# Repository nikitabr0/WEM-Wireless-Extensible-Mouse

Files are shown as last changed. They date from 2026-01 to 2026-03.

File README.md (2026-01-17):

# WEM-Wireless-Extensible-Mouse
A computer mouse, that can be connected via USB-C, Bluetooth or a 2.GHz USB dongle. It will have some additional buttons and extra GPIO header(s) for adding more functionality later on.

## Licensing

- **Firmware:** Licensed under the MIT License — see `LICENSE.firmware`.
- **Hardware:** Licensed under CERN-OHL-P-V2 (Permissive) — see https://cern.ch/cern-ohl and `LICENSE.hardware`.

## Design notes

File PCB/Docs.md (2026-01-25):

[nRF52840 QFN73](https://docs.nordicsemi.com/bundle/ps_nrf52840/page/keyfeatures_html5.html)

[MCP73871 2CC](https://ww1.microchip.com/downloads/en/DeviceDoc/MCP73871-Data-Sheet-20002090E.pdf)

[PAW3395DM-T6QU](https://www.lcsc.com/datasheet/C41346211.pdf)

[MDD(Microdiode Semiconductor) SMF5.0A](https://www.lcsc.com/datasheet/C193402.pdf)

[Littelfuse 1206L110THYR](https://www.lcsc.com/datasheet/C126818.pdf)

[Leiditech TPD2EUSB30DRTR](https://www.lcsc.com/datasheet/C3040102.pdf)

[MCP1801T-3302I/OT](https://ww1.microchip.com/downloads/en/DeviceDoc/22051D.pdf)

[Kailh Silent Micro Switch MI627301D07](https://www.kailhswitch.com/info/kailh-silent-micro-switch-mi627301d-35964852.html)

[LT1761ES5-2](https://www.analog.com/media/en/technical-documentation/data-sheets/1761sff.pdf)

[ALPSALPINE SSSS223600](https://www.lcsc.com/datasheet/C255513.pdf)

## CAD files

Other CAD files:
CAD/WEM.FCStd

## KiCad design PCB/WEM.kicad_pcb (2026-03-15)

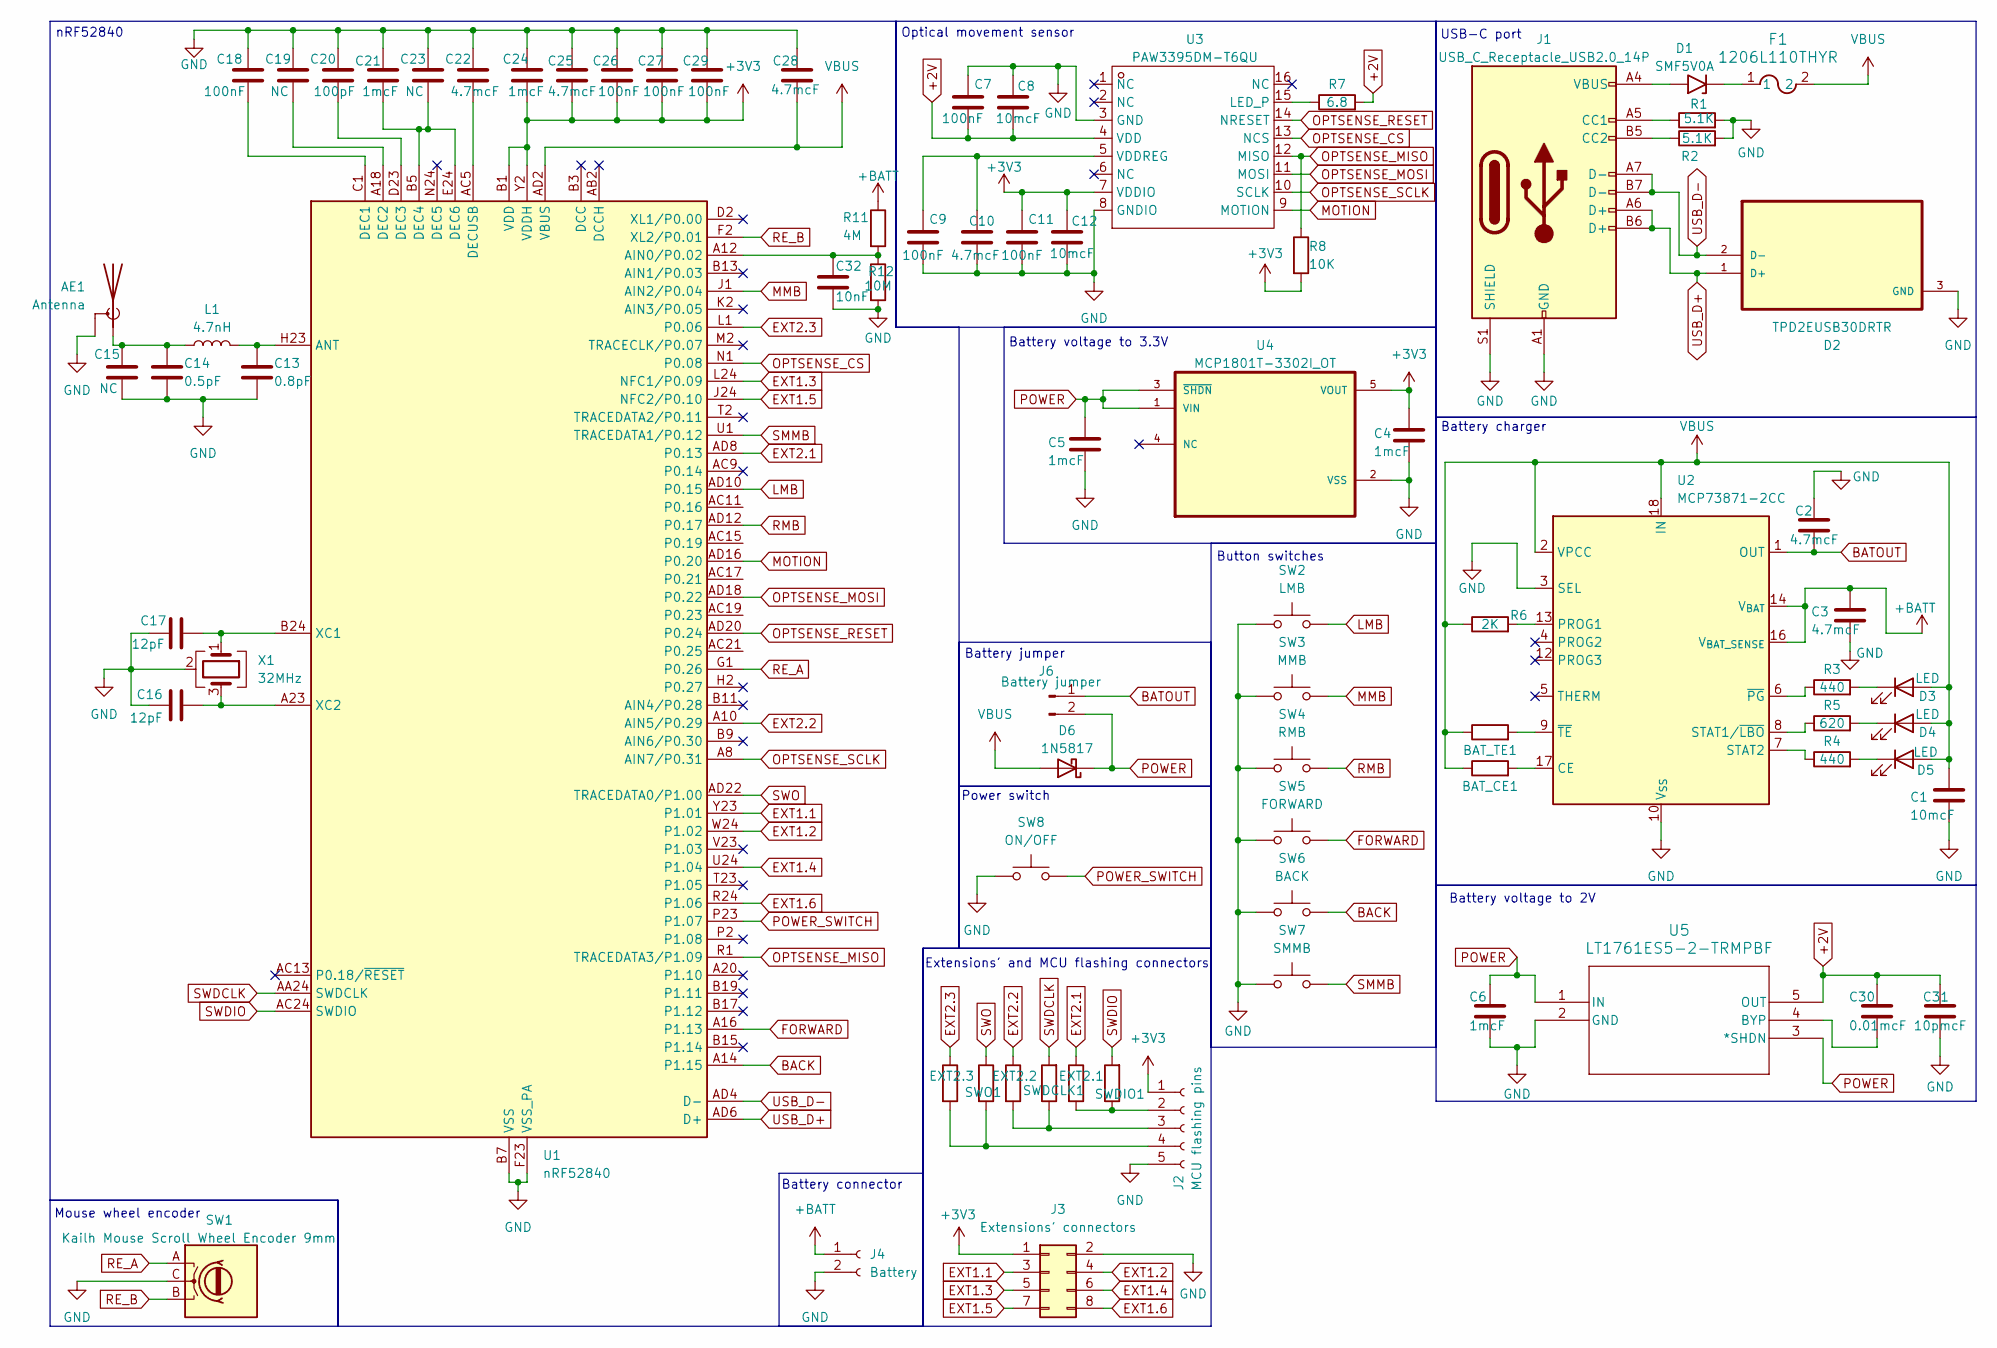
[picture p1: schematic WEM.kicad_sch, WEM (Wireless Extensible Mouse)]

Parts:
AE1: Antenna; Texas_SWRA117D_2.4GHz_Right
BAT_CE1: 0; R_0805_2012Metric_Pad1.20x1.40mm_HandSolder
BAT_TE1: 0; R_0805_2012Metric_Pad1.20x1.40mm_HandSolder
C1, C8, C12: 10mcF; C_0805_2012Metric_Pad1.18x1.45mm_HandSolder
C2, C3, C10: 4.7mcF; C_0805_2012Metric_Pad1.18x1.45mm_HandSolder
C4, C5, C6: 1mcF; C_0805_2012Metric_Pad1.18x1.45mm_HandSolder
C7, C9, C11: 100nF; C_0805_2012Metric_Pad1.18x1.45mm_HandSolder
C13: 0.8pF; C_0603_1608Metric_Pad1.08x0.95mm_HandSolder
C14: 0.5pF; C_0603_1608Metric_Pad1.08x0.95mm_HandSolder
C15, C19, C23: NC; C_0603_1608Metric_Pad1.08x0.95mm_HandSolder
C16, C17: 12pF; C_0603_1608Metric_Pad1.08x0.95mm_HandSolder
C18, C26, C27, C29: 100nF; C_0603_1608Metric_Pad1.08x0.95mm_HandSolder
C20: 100pF; C_0603_1608Metric_Pad1.08x0.95mm_HandSolder
C21, C24: 1mcF; C_0603_1608Metric_Pad1.08x0.95mm_HandSolder
C22, C25, C28: 4.7mcF; C_0603_1608Metric_Pad1.08x0.95mm_HandSolder
C30: 0.01mcF; C_0805_2012Metric_Pad1.18x1.45mm_HandSolder
C31: 10pmcF; C_0805_2012Metric_Pad1.18x1.45mm_HandSolder
C32: 10nF; C_0805_2012Metric_Pad1.18x1.45mm_HandSolder
D1: SMF5V0A; D_SMF
D2: TPD2EUSB30DRTR; SOTFL35P100X50-3N
D3, D4, D5: LED; LED_0805_2012Metric_Pad1.15x1.40mm_HandSolder
D6: 1N5817; D_SOD-323F
EXT2.1, EXT2.2, EXT2.3: 0; R_0805_2012Metric_Pad1.20x1.40mm_HandSolder
F1: 1206L110THYR; Fuse_1206_3216Metric_Pad1.42x1.75mm_HandSolder
J1: USB_C_Receptacle_USB2.0_14P; USB_C_Receptacle_GCT_USB4085
J2: MCU flashing pins; PinSocket_1x05_P2.54mm_Vertical
J3: Extensions' connectors; PinSocket_2x04_P2.54mm_Vertical
J4: Battery; JST_XH_B2B-XH-A_1x02_P2.50mm_Vertical
J6: Battery jumper; PinHeader_1x02_P2.54mm_Vertical
L1: 4.7nH; L_0402_1005Metric_Pad0.77x0.64mm_HandSolder
R1, R2: 5.1K; R_0805_2012Metric_Pad1.20x1.40mm_HandSolder
R3, R4: 440; R_0805_2012Metric_Pad1.20x1.40mm_HandSolder
R5: 620; R_0805_2012Metric_Pad1.20x1.40mm_HandSolder
R6: 2K; R_0805_2012Metric_Pad1.20x1.40mm_HandSolder
R7: 6.8; R_0805_2012Metric_Pad1.20x1.40mm_HandSolder
R8: 10K; R_0805_2012Metric_Pad1.20x1.40mm_HandSolder
R11: 4M; R_0805_2012Metric_Pad1.20x1.40mm_HandSolder
R12: 10M; R_0805_2012Metric_Pad1.20x1.40mm_HandSolder
SW1: Kailh Mouse Scroll Wheel Encoder 9mm
SW2: LMB; Kailh MI627301D07
SW3: MMB; Kailh MI627301D07
SW4: RMB; Kailh MI627301D07
SW5: FORWARD; Kailh MI627301D07
SW6: BACK; Kailh MI627301D07
SW7: SMMB; Kailh MI627301D07
SW8: ON/OFF; Kailh MI627301D07
SWDCLK1: 0; R_0805_2012Metric_Pad1.20x1.40mm_HandSolder
SWDIO1: 0; R_0805_2012Metric_Pad1.20x1.40mm_HandSolder
SWO1: 0; R_0805_2012Metric_Pad1.20x1.40mm_HandSolder
U1: nRF52840; Nordic_AQFN-73-1EP_7x7mm_P0.5mm
U2: MCP73871-2CC; QFN-20-1EP_4x4mm_P0.5mm_EP2.5x2.5mm
U3: PAW3395DM-T6QU; DIP-16_PAW3395DM-T6QU; Manufacturer Part PAW3395DM-T6QU; LCSC Part Name PAW3395DM-T6QU
U4: MCP1801T-3302I_OT; SOT-23-5_MC_MCH-M
U5: LT1761ES5-2-TRMPBF; S_5_ADI
X1: 32MHz; Crystal_SMD_2016-4Pin_2.0x1.6mm

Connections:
+2V: C7.2, C8.2, C30.1, C31.1, R7.2, U3.4 (VDD), U5.5 (OUT)
+3V3: C4.1, C11.1, C12.1, C24.2, C25.2, C26.2, C27.2, C29.2, J2.1, J3.1, R8.2, U1.A22 (VDD), U1.AD14 (VDD), U1.AD23 (VDD), U1.B1 (VDD), U1.W1 (VDD), U1.Y2 (VDDH), U3.7 (VDDIO), U4.5 (VOUT)
+BATT: C3.2, J4.1, R11.1, U2.14 (V_{BAT}), U2.15 (V_{BAT}), U2.16 (V_{BAT_SENSE})
BACK: SW6.2, U1.A14 (P1.15)
BATOUT: C2.1, J6.1, U2.1 (OUT), U2.20 (OUT)
EXT1.1: J3.3, U1.Y23 (P1.01)
EXT1.2: J3.4, U1.W24 (P1.02)
EXT1.3: J3.5, U1.L24 (NFC1/P0.09)
EXT1.4: J3.6, U1.U24 (P1.04)
EXT1.5: J3.7, U1.J24 (NFC2/P0.10)
EXT1.6: J3.8, U1.R24 (P1.06)
EXT2.1: EXT2.1.1, U1.AD8 (P0.13)
EXT2.2: EXT2.2.1, U1.A10 (AIN5/P0.29)
EXT2.3: EXT2.3.1, U1.L1 (P0.06)
FORWARD: SW5.2, U1.A16 (P1.13)
GND: AE1.2 (Shield), C1.2, C2.2, C3.1, C4.2, C5.2, C6.2, C7.1, C8.1, C9.2, C10.2, C11.2, C12.2, C13.2, C14.2, C15.2, C16.1, C17.1, C18.1, C19.1, C20.1, C21.1, C22.1, C23.1, C24.1, C25.1, C26.1, C27.1, C28.1, C29.1, C31.2, C32.2, D2.3 (GND), J1.A1 (GND), J1.A12 (GND), J1.B1 (GND), J1.B12 (GND), J1.S1 (SHIELD), J2.5, J3.2, J4.2, R1.2, R2.2, R12.2, SW1.C, SW2.1, SW3.1, SW4.1, SW5.1, SW6.1, SW7.1, SW8.1, U1.B7 (VSS), U1.EP (VSS), U1.F23 (VSS_PA), U2.3 (SEL), U2.10 (V_{SS}), U2.11 (V_{SS}), U2.21 (V_{SS}), U3.3 (GND), U3.8 (GNDIO), U4.2 (VSS), U5.2 (GND), X1.2 (G), X1.4 (G)
LMB: SW2.2, U1.AD10 (P0.15)
MMB: SW3.2, U1.J1 (AIN2/P0.04)
MOTION: U1.AD16 (P0.20), U3.9 (MOTION)
unnamed: AE1.1 (A), C14.1, C15.1, L1.1
unnamed: D1.1 (A1), F1.1
unnamed: D1.2 (A2), J1.A4 (VBUS), J1.A9 (VBUS), J1.B4 (VBUS), J1.B9 (VBUS)
unnamed: D3.1 (K), R3.2
unnamed: D4.1 (K), R5.2
unnamed: D5.1 (K), R4.2
unnamed: J1.A5 (CC1), R1.1
unnamed: J1.B5 (CC2), R2.1
unnamed: EXT2.1.2, J2.2, SWDIO1.1
unnamed: EXT2.2.2, J2.3, SWDCLK1.1
unnamed: EXT2.3.2, J2.4, SWO1.2
unnamed: C32.1, R11.2, R12.1, U1.A12 (AIN0/P0.02)
unnamed: C13.1, L1.2, U1.H23 (ANT)
unnamed: C18.2, U1.C1 (DEC1)
unnamed: C19.2, U1.A18 (DEC2)
unnamed: C20.2, U1.D23 (DEC3)
unnamed: C21.2, C23.2, U1.B5 (DEC4), U1.E24 (DEC6)
unnamed: C22.2, U1.AC5 (DECUSB)
unnamed: C17.2, U1.B24 (XC1), X1.1
unnamed: C16.2, U1.A23 (XC2), X1.3
unnamed: BAT_CE1.2, U2.17 (CE)
unnamed: R6.2, U2.13 (PROG1)
unnamed: R5.1, U2.8 (STAT1/~LBO)
unnamed: R4.1, U2.7 (STAT2)
unnamed: R3.1, U2.6 (~PG)
unnamed: BAT_TE1.2, U2.9 (~TE)
unnamed: R7.1, U3.15 (LED_P)
unnamed: C9.1, C10.1, U3.5 (VDDREG)
unnamed: C30.2, U5.4 (BYP)
OPTSENSE_CS: U1.N1 (P0.08), U3.13 (NCS)
OPTSENSE_MISO: R8.1, U1.R1 (TRACEDATA3/P1.09), U3.12 (MISO)
OPTSENSE_MOSI: U1.AD18 (P0.22), U3.11 (MOSI)
OPTSENSE_RESET: U1.AD20 (P0.24), U3.14 (NRESET)
OPTSENSE_SCLK: U1.A8 (AIN7/P0.31), U3.10 (SCLK)
POWER: C5.1, C6.1, D6.1 (K), J6.2, U4.1 (VIN), U4.3 (~SHDN), U5.1 (IN), U5.3 (*SHDN)
POWER_SWITCH: SW8.2, U1.P23 (P1.07)
RE_A: SW1.A, U1.G1 (P0.26)
RE_B: SW1.B, U1.F2 (XL2/P0.01)
RMB: SW4.2, U1.AD12 (P0.17)
SMMB: SW7.2, U1.U1 (TRACEDATA1/P0.12)
SWDCLK: SWDCLK1.2, U1.AA24 (SWDCLK)
SWDIO: SWDIO1.2, U1.AC24 (SWDIO)
SWO: SWO1.1, U1.AD22 (TRACEDATA0/P1.00)
USB_D+: D2.1 (D+), J1.A6 (D+), J1.B6 (D+), U1.AD6 (D+)
USB_D-: D2.2 (D-), J1.A7 (D-), J1.B7 (D-), U1.AD4 (D-)
VBUS: BAT_CE1.1, BAT_TE1.1, C1.1, C28.2, D3.2 (A), D4.2 (A), D5.2 (A), D6.2 (A), F1.2, R6.1, U1.AD2 (VBUS), U2.2 (VPCC), U2.18 (IN), U2.19 (IN)

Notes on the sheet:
Button switches
Optical movement sensor
Battery voltage to 2V
Power switch
USB-C port
Battery connector
Battery voltage to 3.3V
Battery charger
Extensions' and MCU flashing connectors
Battery jumper
nRF52840
Mouse wheel encoder

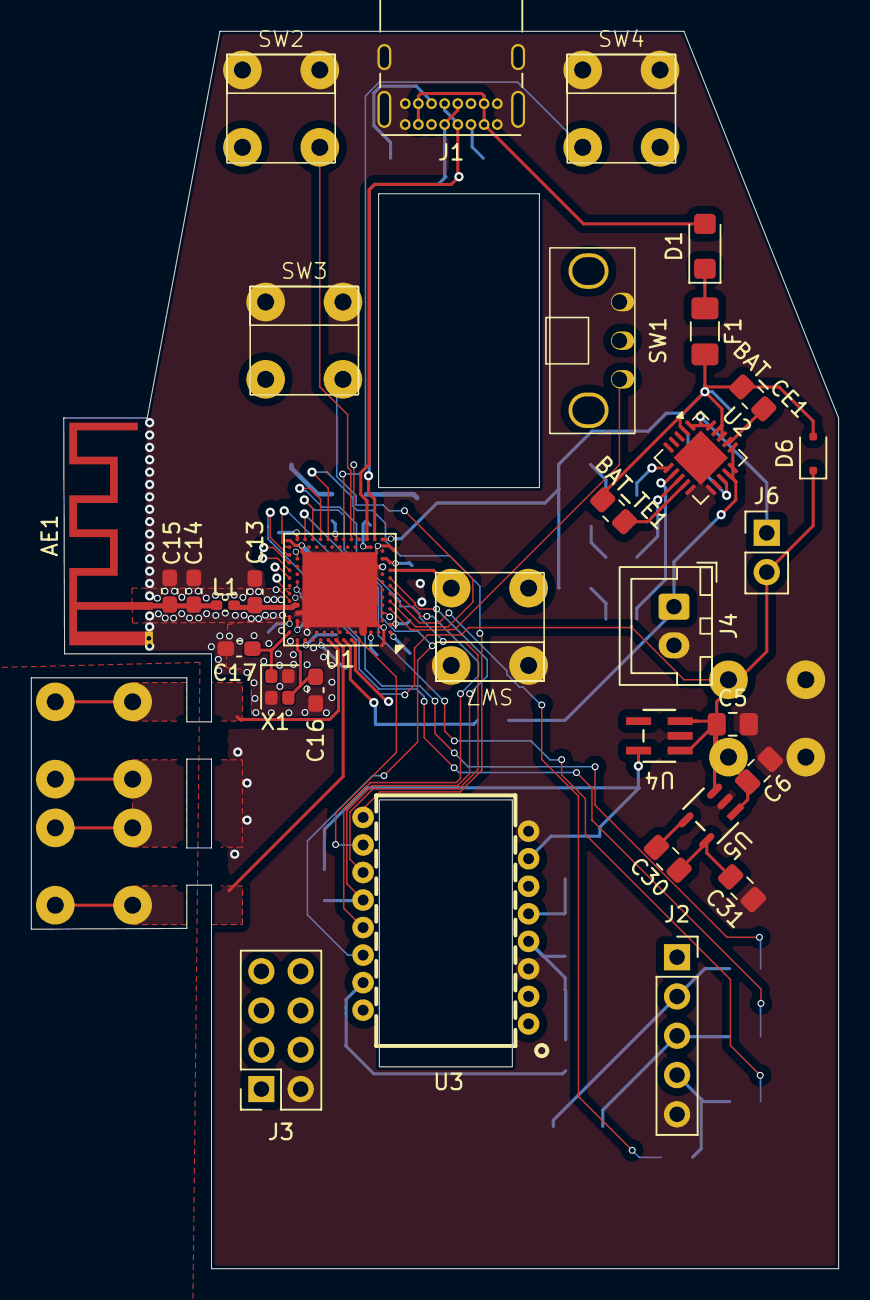
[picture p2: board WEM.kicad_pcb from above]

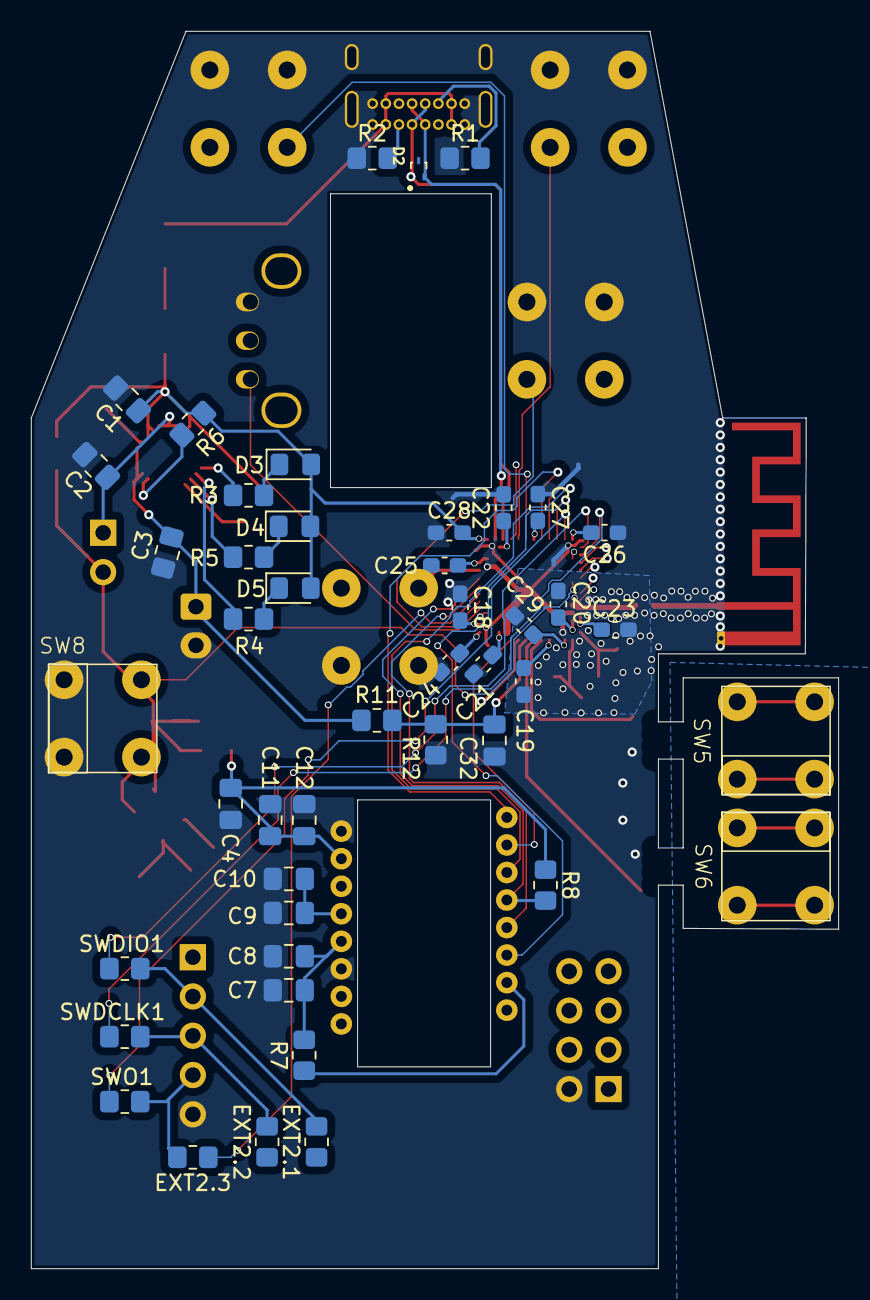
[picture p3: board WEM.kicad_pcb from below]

Board: 2 copper layers, 52.2 x 80.0 mm, 78 parts (46 on the bottom side), 65 nets.

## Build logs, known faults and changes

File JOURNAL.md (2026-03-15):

# Motivation

About a month ago I started the MAWK (Modular Analog Wireless Keyboard) project, but at one point I realised it was getting too complex for me to even try finishing it with my current skills. So I decided to start WEM (Wireless Extensible Mouse) project with the goal of learning power management, RF circuits and SMD soldering to be able to use barebones MCU chips in my projects.

# What I've done

## 2026.01.17 - 2h
### Working environment, licences, MCU, firmware

Set up local and GitHub repositories.

Chose licences for firmware (MIT Licence) and hardware (CERN Open Hardware Licence Version 2 - Permissive)

Decided to use [nRF52840 QFN73](https://www.aliexpress.com/item/1005005069398861.html) for its good connectivity options and because I am going to use it later MAWK, so I can already gain some experience with it.

For the firmware I chose ZMK. It supports USB, BLE and allows using proprietary 2.GHz radio protocols, which I plan to employ fo the 2.4GHz USB dongle.

## 2026.01.18 - 2h
### Started schematic design

For battery charging I will be using [MCP73871 2CC](https://www.aliexpress.com/item/1005008336731440.html).

For the optical sensor I chose [PAW3395DM-T6QU with a LM19-LSI lens](https://www.aliexpress.com/item/1005009206404384.html)

USB protections: [MDD(Microdiode Semiconductor) SMF5.0A](https://www.lcsc.com/product-detail/C193402.html), [Littelfuse 1206L110THYR](https://www.lcsc.com/product-detail/C126818.html) on VBUS and [Leiditech TPD2EUSB30DRTR](https://www.lcsc.com/product-detail/C3040102.html) on data lines.

So far I've chosen the main componenets and done the USB-C port schematics.

2026.01.18 schematic

## 2026.01.22 - 3h
### Voltage regulators, continuing with schematic

I found the MCP1801 series voltage regulators, which I'll be using to convert battery voltage to 3.3V and 1.8V.

I'll be using [MCP1801T-3302I/OT](https://www.lcsc.com/product-detail/C3040615.html) and [MCP1801T-1802I/OT](https://www.lcsc.com/product-detail/C556903.html).

For the button switches I decided to go with Omron D2Fs, as they're cheap, reliable and while they're not created for mouse buttons, they're widely available.

I implemented the battery charger and voltage regulators in the schematic and spent some time researching antennas. I'll try to fit a F-antenna in the up-left corner for the best RF characteristics.

2026.01.22 schematic

## 2026.01.23 2.5h
### Mouse wheel encoder and schematics

Found [Kailh Mouse Scroll Wheel Encoder 9mm](https://www.aliexpress.com/item/1005001852115432.html), which I will be using. It's quite popular in DIY computer mice.

Added links to components' documentations to `PCB/Docs.md`.

The PAW3395DM-T6QU optical movement sensor needs a resistor to set the current to 50mA, but the datasheet provides resistances only for 2V and 1.9V (I'm using 1.8V). Using linear interpolation gave a resisitor value of 4.4 Ohms. Since the datasheet recommends a 1% tolerance (E96), I'll use a 4.53 Ohm resitor, just to be safe.

Completed optical sensor, mouse wheel encoder and extensions'/MCU flashing connectors. Also decided to use 0 Ohm resistors instead of solder bridge jumpers.

2026.01.23 schematic

## 2026.01.24 1.6h
### Took apart my current mouse and more schematics

Continued with schematics. Added switches and the recommended MCU wiring. Had to shift the symbols around to make some room for the MCU.

Made an explorative surgery on my current mouse and based on that made some decisions:

1. I will use [11mm version](https://www.aliexpress.com/item/1005007462295852.html) of the rotary encoder, the 9mm would probably be a little too short. Also I found a cheaper offer.

2. I will use [Kailh Silent Micro Switch MI627301D07](https://www.aliexpress.com/item/1005010180023487.html) instead of D2Fs. My current mouse has these and they make close to zero noise, which I really like.

Also realised that the last two schematics snapshots had the wrong date.
2026.01.24 schematic

## 2026.01.25 4.5h
### Finished schematics

Decided to switch to [LT1761ES5-2](https://www.aliexpress.com/item/1005009716344832.html) for the optical sensor voltage regulator. It provides 2V instead of 1.8V, which should mean a more stable performance.

Will be using [this 1000mAh 3.7V Li-Po battery](https://www.aliexpress.com/item/32988574923.html).

Modified the power path:
1. [The ALPSALPINE SSSS223600 switch](https://www.lcsc.com/product-detail/C255513.html) allows to switch off the entire mouse, when it runs on battery power and also controls wireless communication mode.
2. [The 1N5817 diode](https://www.lcsc.com/product-detail/C727114.html) provides bypass power from USB at all times regardless of the switch's state.

Found some componenets:
- [Antenna inductor](https://www.lcsc.com/product-detail/C40353066.html)
- [32MHz crystal](https://www.lcsc.com/product-detail/C37635331.html)
- [Female USB-C](https://www.lcsc.com/product-detail/C7095263.html)

LEDs:
- [Blue - charging](https://www.lcsc.com/product-detail/C108412.html)
- [Green - power good](https://www.lcsc.com/product-detail/C5123492.html)
- [Red - low battery](https://www.lcsc.com/product-detail/C130114.html)

Added battery connector, finished the MCU wiring, made a footprint for Kailh switches and added them to the schematic.

2026.01.25 schematic
2026.01.25 PCB

I hope I'm finally done with the schematics!

## 2026.01.30 1h:
### A few schematics modifications and starting with firmware

After familiarising myself with ZMK, I made some changes to the schematic:
1. Battery jumper to disable battery or add a battery switch and a soft power button to use ZMK's soft shutdown. The idel current draw will be higher, but it should be safer.
2. Added a battery voltage divider on nRF's ADC pin to be able to read battery voltage.

Also I removed some pull-up resistors from the motion sensor, as a better datasheet, I found, indicated, that there's no need for them.

Started writing the firmware. The basics don't seem to be that hard, but I couldn't get it to build properly, as it couldn't find my custom board for some reason. But I'm too tired to deal with it today.

I had to move the whole firmware to a different repo, because of ZMK's build toolchain, so I'll have to change the structure of my project. Though I'm hoping I'll be able to set up ZMK's build toolchain in a container and keep it in this repo.

[For now the firmware is here.](https://github.com/nikitabr0/WEM-ZMK-config)

2026.01.30 schematic
2026.01.30 PCB

## 2026.02.15 5h:
### It's been 2.5 weeks... PCB routing

For the past 3 weeks (mainly weekends) I've been trying to learn ZMK and made some attempts at starting my firmware. So far I've tried writing from scratch, copying other nRF52840 boards and asking (forcing) LLMs (soulless machines) to help me write (write for me) the firmware. Most of the time I was just playing with ZMK to see what will stick. I'm not going to count that time, since it was barely productive. I've learned a lot, but done nothing. Now I've found an actual guide for creating a custom board, so I'm going to try that in a few days.

Yesterday I finally started routing the PCB. So far it's going quite well. I've made multiple mistakes with RF circuitry (stubs, curvy traces, unmatched impedance), but fellow blueprinters pointed them out to me.

Initially I put vias inside nRF's pads, since it's aQFN-73 package has a bunch of pins, that are inaccessible otherwise, but tty7 (this guy helped me the most) reminded me that JLCPCB charges extra for those, so I had to reassign some pins in the schematic, so they would be on the outer edge of the package.

I've tried adding the forward and back butons on a separate mini-PCB, that I would soldered sideways to the main one in order to have the buttons oriented to the side. I am using mousebites to connect the two PCBs in hope, that JLCPCB will be nice and won't ask too much extra for 2 designs in one order.

Next I have to protect the oscillator from RF interference, finish power management, connect the movement sensor and add the last buttons.

2026.02.15 schematic
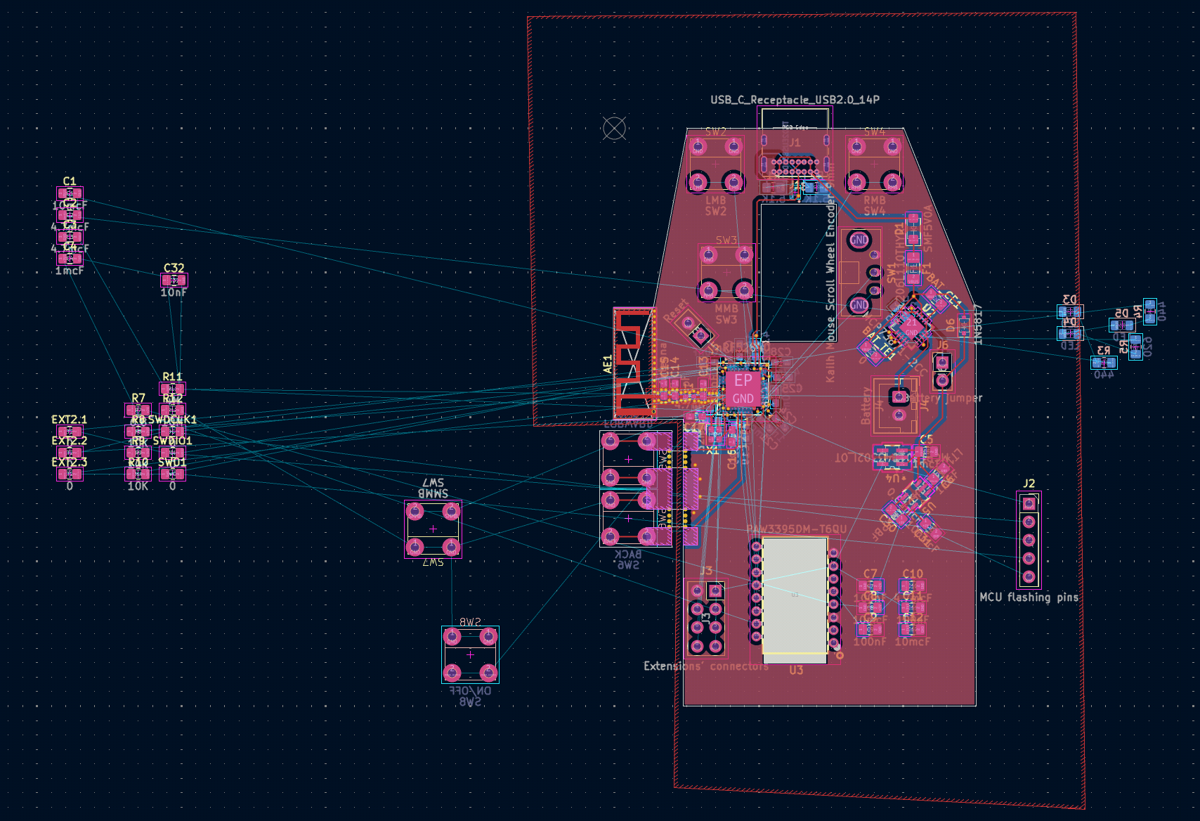
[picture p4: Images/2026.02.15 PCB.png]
2026.02.15 PCB


## 2026.03.15 1.9h:
### Finally back to this project and ... realised my PCB is hopeless

I finally found some time to continue routing, but after almost 2 hours found that the microcontroller region of the PCB is too crowded and I'm going to have to completely reroute it. At one point I tried removing the reset jumper for nRF, but that didn't really help.

I probably won't be able to finish this project before the Blueprint deadline (31st March).

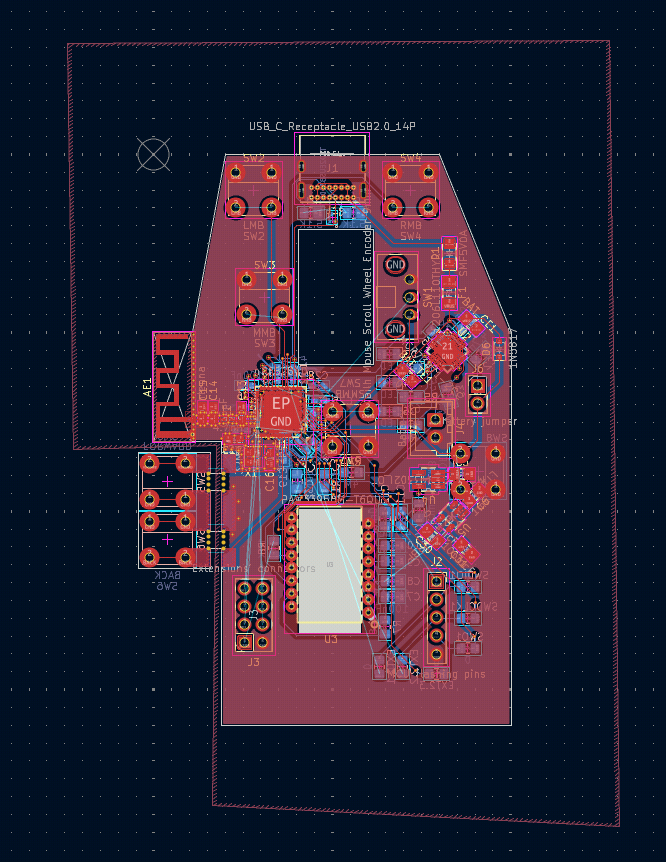
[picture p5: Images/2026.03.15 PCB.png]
2026.03.15 PCB


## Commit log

2026-01-17 Working environment, licences, MCU, firmware
    [WEM.FCStd, WEM.kicad_pcb, WEM.kicad_sch]
2026-01-18 Started schematic design
    [WEM.kicad_sch]
2026-01-22 Voltage regulators and schematic progress
    [WEM.kicad_sch]
2026-01-23 Mouse wheel encoder amd more work on schematics
    [WEM.kicad_sch]
2026-01-24 More schematics
2026-01-25 Finished schematics
    [WEM.kicad_pcb, WEM.kicad_sch]
2026-01-30 Schematics modifications and firmware
    [WEM.kicad_pcb, WEM.kicad_sch]
2026-02-14 Started PCB routing
    [WEM.kicad_pcb, WEM.kicad_sch]
2026-03-15 Continued routing. It's hopeless
    [WEM.kicad_pcb, WEM.kicad_sch]
